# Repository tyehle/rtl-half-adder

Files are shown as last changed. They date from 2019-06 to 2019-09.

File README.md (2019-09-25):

# RTL Half Adder Circuit

board-render-f
board-render-b

A half adder circuit implemented with resistor transistor logic. All essential logic is on the front with through hole parts, and additional lights are surface mount on the back.

# Schematic
schematic
smd-leds

# BOM

| Reference | Value | Part Number | Quantity | Datasheet | Link |
|---|---|---|---|---|---|
| BT1 | Battery_Cell | BAT-HLD-012-THM | 1 | [Datasheet](https://linxtechnologies.com/wp/wp-content/uploads/bat-hld-012-thm.pdf) | [mouser.com](https://www.mouser.com/ProductDetail/BAT-HLD-012-THM) |
| D1 D2 | Red | LTL-4223 | 2 | [Datasheet](https://optoelectronics.liteon.com/upload/download/DS20-2003-313/LTL-4223-032A.pdf) | [mouser.com](https://www.mouser.com/ProductDetail/LTL-4223) |
| D3 D4 | Green | LTL-4233 | 2 | [Datasheet](https://optoelectronics.liteon.com/upload/download/DS-20-92-1097/4233DG.pdf) | [mouser.com](https://www.mouser.com/ProductDetail/LTL-4233) |
| D10 D11 D12 D13 D14 D15 D16 D17 D18 D19 D20 D21 D22 D23 D24 D25 D26 D27 D5 D6 D7 D8 D9 | Yellow | LTST-C230KSKT | 23 | [Datasheet](https://optoelectronics.liteon.com/upload/download/DS22-2000-254/LTST-C230KSKT.pdf) | [mouser.com](https://www.mouser.com/ProductDetail/859-LTST-C230KSKT) |
| Q16 Q17 Q18 Q19 | Q_NPN_BEC | MMBT3904,215 | 4 | [Datasheet](https://assets.nexperia.com/documents/data-sheet/MMBT3904.pdf) | [mouser.com](https://www.mouser.com/ProductDetail/MMBT3904215) |
| Q1 Q10 Q11 Q12 Q13 Q14 Q15 Q2 Q3 Q4 Q5 Q6 Q7 Q8 Q9 | Q_NPN_EBC | 2N3904BU | 15 | [Datasheet](https://www.onsemi.com/pub/Collateral/2N3904-D.pdf) | [mouser.com](https://www.mouser.com/ProductDetail/2N3904BU) |
| R2 R26 R27 R4 | 510 | CFR-25JR-52-510R  | 4 | [Datasheet](http://www.yageo.com/NewPortal/yageodocoutput?fileName=/pdf/throughhole/Yageo_LR_CFR_2013.pdf) | [mouser.com](https://www.mouser.com/ProductDetail/CFR-25JR-52-510R) |
| R28 R31 R35 R38 | 10k | CR0805-FX-1002ELF | 4 | [Datasheet](https://www.bourns.com/pdfs/chpreztr.pdf) | [mouser.com](https://www.mouser.com/ProductDetail/652-CR0805FX-1002ELF) |
| R29 R30 R32 R33 R34 R36 R37 R39 R40 R41 R42 R43 R44 R45 R46 R47 R48 R49 R50 R51 R52 R53 R54 | 510 | CR0805-FX-5100ELF | 23 | [Datasheet](https://www.bourns.com/pdfs/chpreztr.pdf) | [mouser.com](https://www.mouser.com/ProductDetail/652-CR0805FX-5100ELF) |
| R1 R10 R11 R13 R14 R15 R16 R19 R21 R22 R24 R25 R3 R5 R6 R7 R8 | 10k | CFR-25JT-52-10K | 17 | [Datasheet](http://www.yageo.com/NewPortal/yageodocoutput?fileName=/pdf/throughhole/Yageo_LR_CFR_2013.pdf) | [mouser.com](https://www.mouser.com/ProductDetail/CFR-25JT-52-10K) |
| R12 R17 R18 R20 R23 R9 | 1k | CFR-25JT-52-1K | 6 | [Datasheet](http://www.yageo.com/NewPortal/yageodocoutput?fileName=/pdf/throughhole/Yageo_LR_CFR_2013.pdf) | [mouser.com](https://www.mouser.com/ProductDetail/CFR-25JT-52-1K) |
| SW1 SW2 SW3 | SW_SPDT | EG1218 | 3 | [Datasheet](https://www.e-switch.com/system/asset/product_line/data_sheet/119/EG.pdf) | [mouser.com](https://www.mouser.com/ProductDetail/EG1218) |

# Assembly notes
[PDF](docs/rtl-half-adder-assembly.pdf)

# LICENSE
<a rel="license" href="http://creativecommons.org/licenses/by-nc-sa/4.0/">

</a>

This work is licensed under a [Creative Commons Attribution-NonCommercial-ShareAlike 4.0 International License](http://creativecommons.org/licenses/by-nc-sa/4.0/).

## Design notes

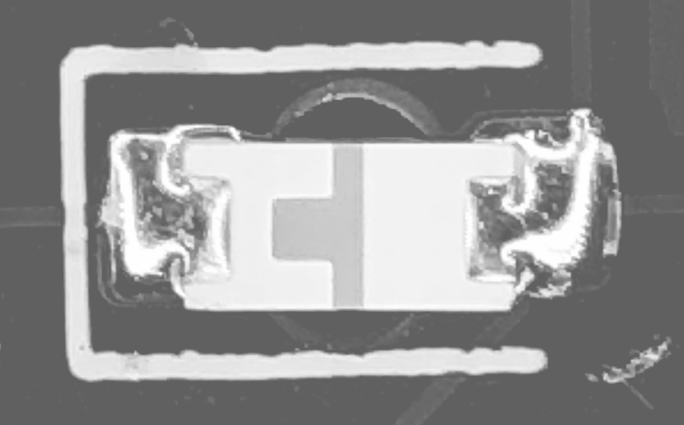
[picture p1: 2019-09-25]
docs/smd-led.jpg

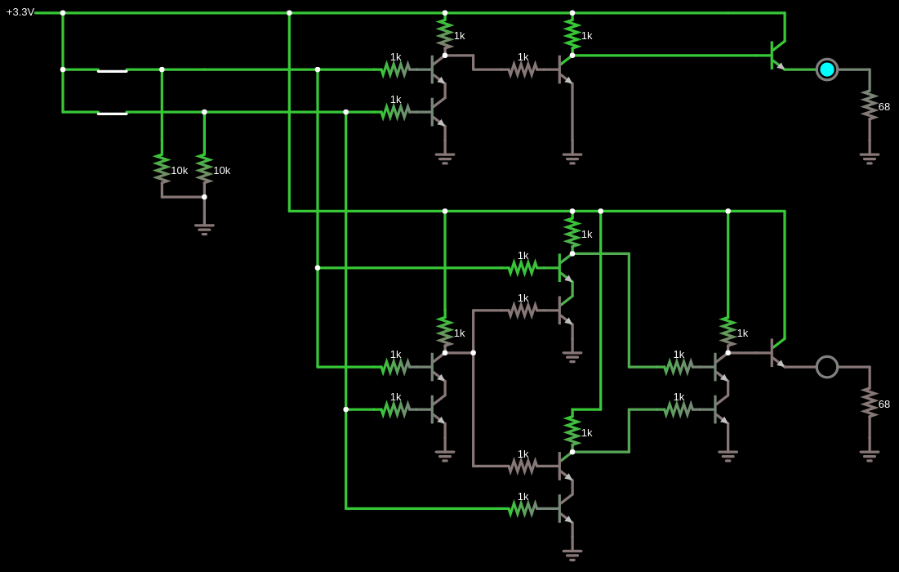
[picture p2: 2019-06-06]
falstad.png

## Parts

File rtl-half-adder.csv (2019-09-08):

Reference | Quantity | Value | Footprint | Datasheet | Link
BT1 | 1 | Battery_Cell | --Project:BatteryHolder_CR1220_THT | https://linxtechnologies.com/wp/wp-content/uploads/bat-hld-012-thm.pdf | https://www.mouser.com/ProductDetail/BAT-HLD-012-THM
D1 D2 | 2 | Red | LED_THT:LED_D5.0mm | https://optoelectronics.liteon.com/upload/download/DS20-2003-313/LTL-4223-032A.pdf | https://www.mouser.com/ProductDetail/LTL-4223
D3 D4 | 2 | Green | LED_THT:LED_D5.0mm | https://optoelectronics.liteon.com/upload/download/DS-20-92-1097/4233DG.pdf | https://www.mouser.com/ProductDetail/LTL-4233
D10 D11 D12 D13 D14 D15 D16 D17 D18 D19 D20 D21 D22 D23 D24 D25 D26 D27 D5 D6 D7 D8 D9 | 23 | Yellow | --Project:LED_1206_ReverseMountSquare1.5mm_HandSolder | https://optoelectronics.liteon.com/upload/download/DS22-2000-254/LTST-C230KSKT.pdf | https://www.mouser.com/ProductDetail/859-LTST-C230KSKT
Q16 Q17 Q18 Q19 | 4 | Q_NPN_BEC | Package_TO_SOT_SMD:SOT-23_Handsoldering | https://assets.nexperia.com/documents/data-sheet/MMBT3904.pdf | https://www.mouser.com/ProductDetail/MMBT3904215
Q1 Q10 Q11 Q12 Q13 Q14 Q15 Q2 Q3 Q4 Q5 Q6 Q7 Q8 Q9 | 15 | Q_NPN_EBC | Package_TO_SOT_THT:TO-92_HandSolder | https://www.onsemi.com/pub/Collateral/2N3904-D.pdf | https://www.mouser.com/ProductDetail/2N3904BU
R2 R26 R27 R4 | 4 | 510 | Resistor_THT:R_Axial_DIN0207_L6.3mm_D2.5mm_P7.62mm_Horizontal | http://www.yageo.com/NewPortal/yageodocoutput?fileName=/pdf/throughhole/Yageo_LR_CFR_2013.pdf | https://www.mouser.com/ProductDetail/CFR-25JR-52-510R
R28 R31 R35 R38 | 4 | 10k | Resistor_SMD:R_0805_2012Metric_Pad1.15x1.40mm_HandSolder | https://www.bourns.com/pdfs/chpreztr.pdf | https://www.mouser.com/ProductDetail/652-CR0805FX-1002ELF
R29 R30 R32 R33 R34 R36 R37 R39 R40 R41 R42 R43 R44 R45 R46 R47 R48 R49 R50 R51 R52 R53 R54 | 23 | 510 | Resistor_SMD:R_0805_2012Metric_Pad1.15x1.40mm_HandSolder | https://www.bourns.com/pdfs/chpreztr.pdf | https://www.mouser.com/ProductDetail/652-CR0805FX-5100ELF
R1 R10 R11 R13 R14 R15 R16 R19 R21 R22 R24 R25 R3 R5 R6 R7 R8 | 17 | 10k | Resistor_THT:R_Axial_DIN0207_L6.3mm_D2.5mm_P7.62mm_Horizontal | http://www.yageo.com/NewPortal/yageodocoutput?fileName=/pdf/throughhole/Yageo_LR_CFR_2013.pdf | https://www.mouser.com/ProductDetail/CFR-25JT-52-10K
R12 R17 R18 R20 R23 R9 | 6 | 1k | Resistor_THT:R_Axial_DIN0207_L6.3mm_D2.5mm_P7.62mm_Horizontal | http://www.yageo.com/NewPortal/yageodocoutput?fileName=/pdf/throughhole/Yageo_LR_CFR_2013.pdf | https://www.mouser.com/ProductDetail/CFR-25JT-52-1K
SW1 SW2 SW3 | 3 | SW_SPDT | --Project:SW_EG1218_SPDT | https://www.e-switch.com/system/asset/product_line/data_sheet/119/EG.pdf | https://www.mouser.com/ProductDetail/EG1218

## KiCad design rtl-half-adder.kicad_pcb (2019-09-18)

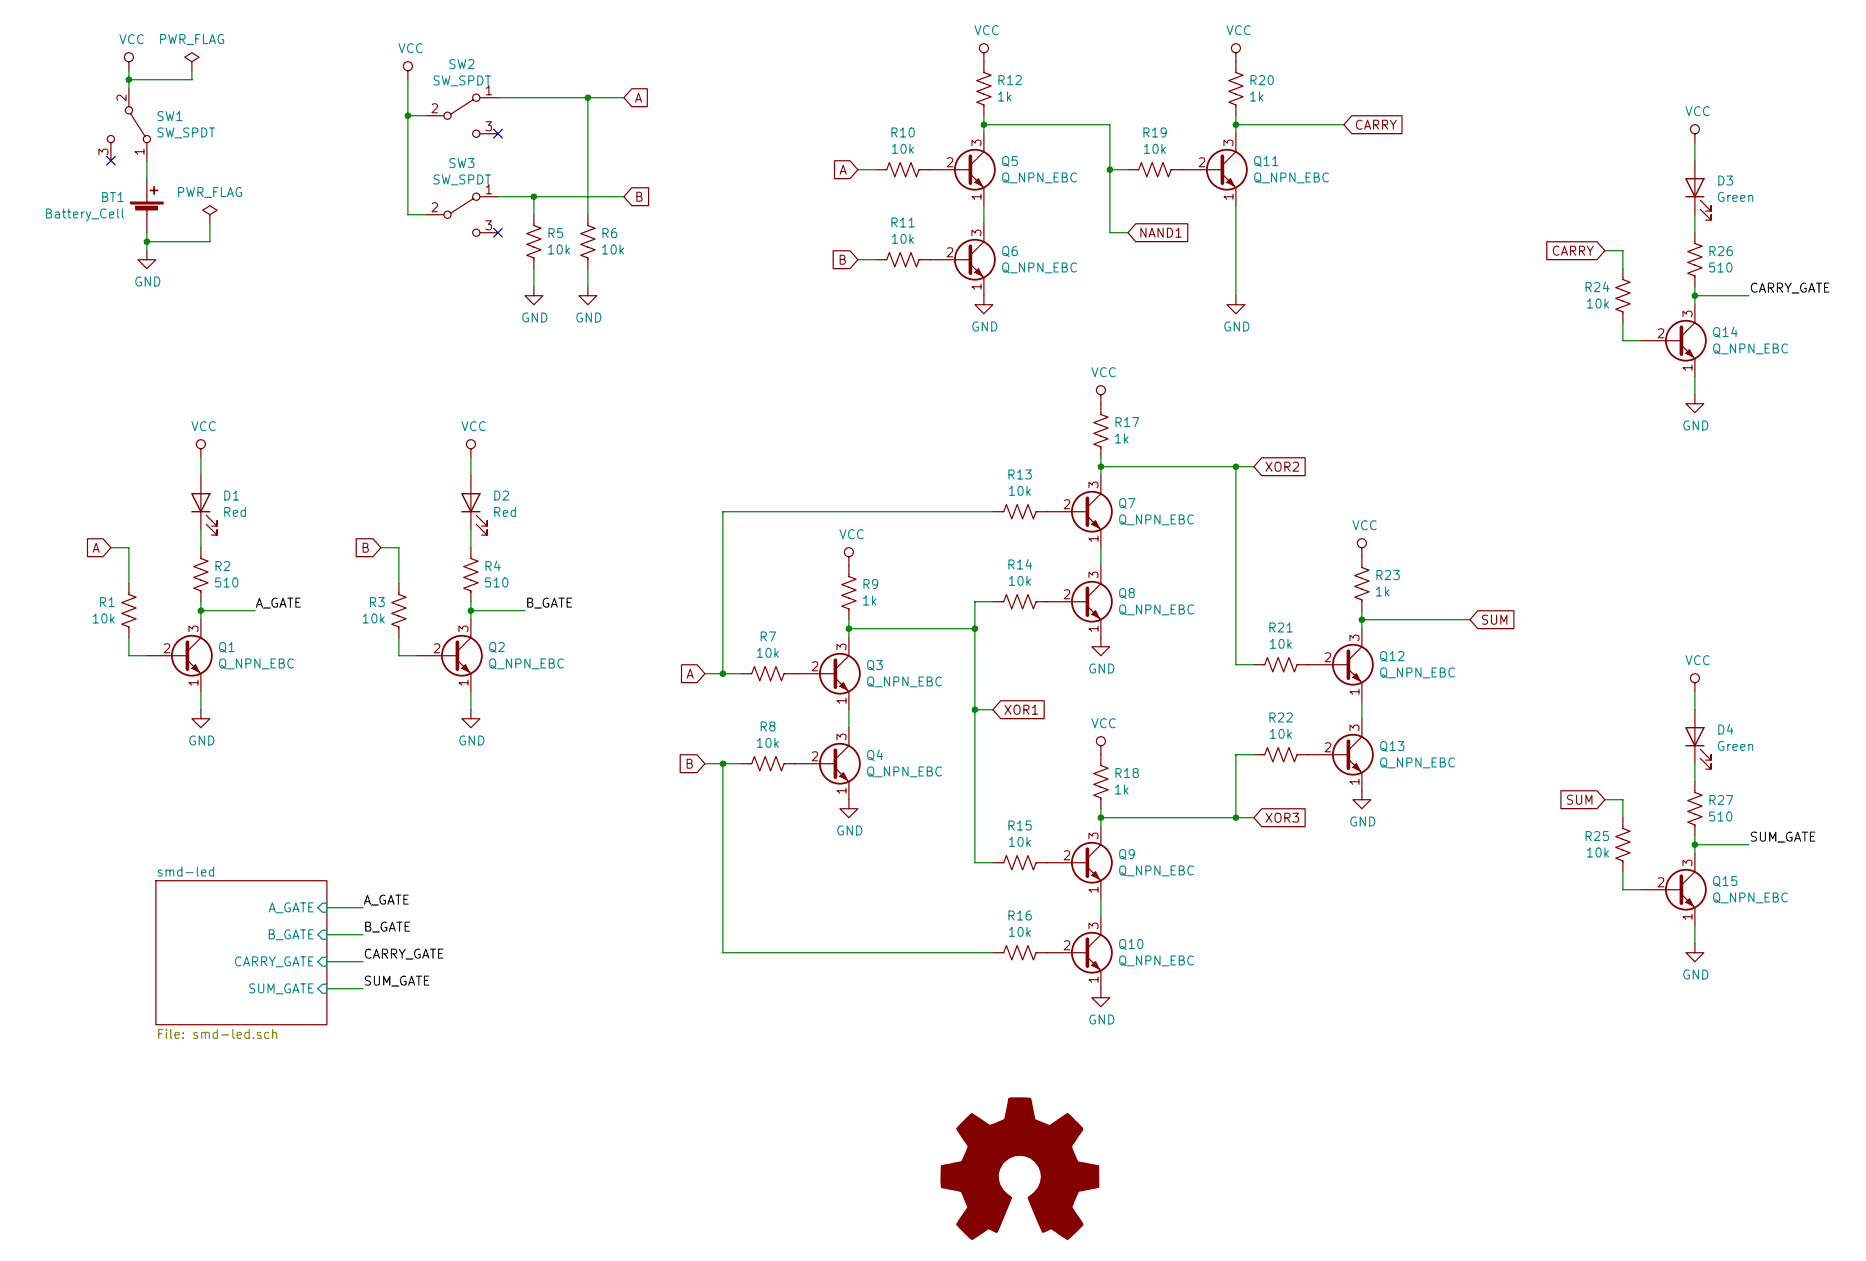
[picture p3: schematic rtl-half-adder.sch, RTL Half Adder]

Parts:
BT1: Battery_Cell; BatteryHolder_CR1220_THT
D1, D2: Red; LED_D5.0mm
D3, D4: Green; LED_D5.0mm
Q1, Q2, Q3, Q4, Q5, Q6, Q7, Q8, Q9, Q10, Q11, Q12, Q13, Q14, Q15: Q_NPN_EBC; TO-92_HandSolder
R1, R3, R5, R6, R7, R8, R10, R11, R13, R14, R15, R16, R19, R21, R22, R24, R25: 10k; R_Axial_DIN0207_L6.3mm_D2.5mm_P7.62mm_Horizontal
R2, R4, R26, R27: 510; R_Axial_DIN0207_L6.3mm_D2.5mm_P7.62mm_Horizontal
R9, R12, R17, R18, R20, R23: 1k; R_Axial_DIN0207_L6.3mm_D2.5mm_P7.62mm_Horizontal
SW1, SW2, SW3: SW_SPDT; SW_EG1218_SPDT

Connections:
/A_GATE: Q1.3 (C), R2.2; also elsewhere on the board
/B_GATE: Q2.3 (C), R4.2; also elsewhere on the board
/CARRY_GATE: Q14.3 (C), R26.2; also elsewhere on the board
/SUM_GATE: Q15.3 (C), R27.2; also elsewhere on the board
A: R1.2, R6.1, R7.2, R10.2, R13.2, SW2.1 (A)
B: R3.2, R5.1, R8.2, R11.2, R16.2, SW3.1 (A)
CARRY: Q11.3 (C), R20.2, R24.2
GND: BT1.2 (-), Q1.1 (E), Q2.1 (E), Q4.1 (E), Q6.1 (E), Q8.1 (E), Q10.1 (E), Q11.1 (E), Q13.1 (E), Q14.1 (E), Q15.1 (E), R5.2, R6.2; also elsewhere on the board
NAND1: Q5.3 (C), R12.2, R19.2; also elsewhere on the board
unnamed: BT1.1 (+), SW1.1 (A)
unnamed: D1.1 (K), R2.1
unnamed: D2.1 (K), R4.1
unnamed: D3.1 (K), R26.1
unnamed: D4.1 (K), R27.1
unnamed: Q1.2 (B), R1.1
unnamed: Q2.2 (B), R3.1
unnamed: Q3.1 (E), Q4.3 (C)
unnamed: Q3.2 (B), R7.1
unnamed: Q4.2 (B), R8.1
unnamed: Q5.1 (E), Q6.3 (C)
unnamed: Q5.2 (B), R10.1
unnamed: Q6.2 (B), R11.1
unnamed: Q7.1 (E), Q8.3 (C)
unnamed: Q7.2 (B), R13.1
unnamed: Q8.2 (B), R14.1
unnamed: Q9.2 (B), R15.1
unnamed: Q10.2 (B), R16.1
unnamed: Q9.1 (E), Q10.3 (C)
unnamed: Q11.2 (B), R19.1
unnamed: Q12.1 (E), Q13.3 (C)
unnamed: Q12.2 (B), R21.1
unnamed: Q13.2 (B), R22.1
unnamed: Q14.2 (B), R24.1
unnamed: Q15.2 (B), R25.1
SUM: Q12.3 (C), R23.2, R25.2
VCC: D1.2 (A), D2.2 (A), D3.2 (A), D4.2 (A), R9.1, R12.1, R17.1, R18.1, R20.1, R23.1, SW1.2 (B), SW2.2 (B), SW3.2 (B); also elsewhere on the board
XOR1: Q3.3 (C), R9.2, R14.2, R15.2; also elsewhere on the board
XOR2: Q7.3 (C), R17.2, R21.2; also elsewhere on the board
XOR3: Q9.3 (C), R18.2, R22.2; also elsewhere on the board

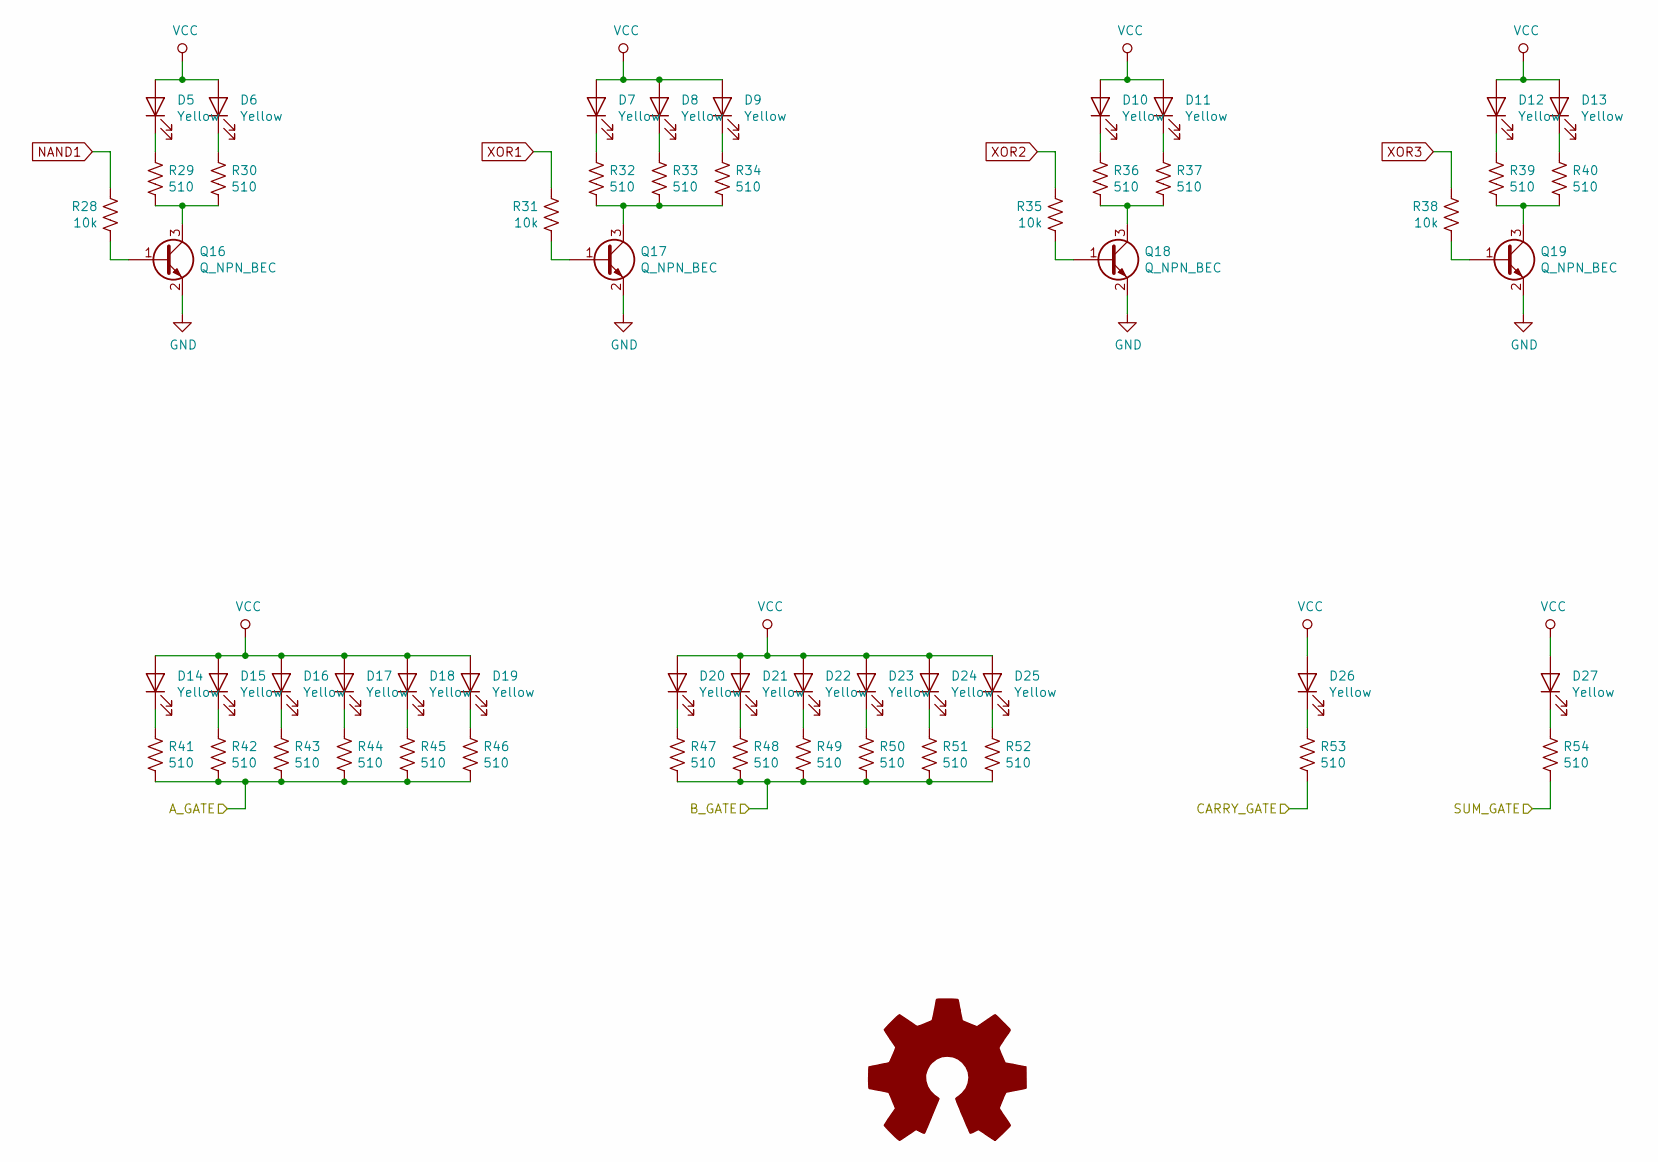
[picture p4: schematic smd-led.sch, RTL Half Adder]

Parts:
D5, D6, D7, D8, D9, D10, D11, D12, D13, D14, D15, D16, D17, D18, D19, D20, D21, D22, D23, D24, D25, D26, D27: Yellow; LED_1206_ReverseMountSquare1.5mm_HandSolder
Q16, Q17, Q18, Q19: Q_NPN_BEC; SOT-23_Handsoldering
R28, R31, R35, R38: 10k; R_0805_2012Metric_Pad1.15x1.40mm_HandSolder
R29, R30, R32, R33, R34, R36, R37, R39, R40, R41, R42, R43, R44, R45, R46, R47, R48, R49, R50, R51, R52, R53, R54: 510; R_0805_2012Metric_Pad1.15x1.40mm_HandSolder

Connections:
/A_GATE: R41.2, R42.2, R43.2, R44.2, R45.2, R46.2; also elsewhere on the board
/B_GATE: R47.2, R48.2, R49.2, R50.2, R51.2, R52.2; also elsewhere on the board
/CARRY_GATE: R53.2; also elsewhere on the board
/SUM_GATE: R54.2; also elsewhere on the board
GND: Q16.2 (E), Q17.2 (E), Q18.2 (E), Q19.2 (E); also elsewhere on the board
NAND1: R28.2; also elsewhere on the board
unnamed: D5.1 (K), R29.1
unnamed: D6.1 (K), R30.1
unnamed: D7.1 (K), R32.1
unnamed: D8.1 (K), R33.1
unnamed: D9.1 (K), R34.1
unnamed: D10.1 (K), R36.1
unnamed: D11.1 (K), R37.1
unnamed: D12.1 (K), R39.1
unnamed: D13.1 (K), R40.1
unnamed: D14.1 (K), R41.1
unnamed: D15.1 (K), R42.1
unnamed: D16.1 (K), R43.1
unnamed: D17.1 (K), R44.1
unnamed: D18.1 (K), R45.1
unnamed: D19.1 (K), R46.1
unnamed: D20.1 (K), R47.1
unnamed: D21.1 (K), R48.1
unnamed: D22.1 (K), R49.1
unnamed: D23.1 (K), R50.1
unnamed: D24.1 (K), R51.1
unnamed: D25.1 (K), R52.1
unnamed: D26.1 (K), R53.1
unnamed: D27.1 (K), R54.1
unnamed: Q16.1 (B), R28.1
unnamed: Q16.3 (C), R29.2, R30.2
unnamed: Q17.1 (B), R31.1
unnamed: Q17.3 (C), R32.2, R33.2, R34.2
unnamed: Q18.1 (B), R35.1
unnamed: Q18.3 (C), R36.2, R37.2
unnamed: Q19.1 (B), R38.1
unnamed: Q19.3 (C), R39.2, R40.2
VCC: D5.2 (A), D6.2 (A), D7.2 (A), D8.2 (A), D9.2 (A), D10.2 (A), D11.2 (A), D12.2 (A), D13.2 (A), D14.2 (A), D15.2 (A), D16.2 (A), D17.2 (A), D18.2 (A), D19.2 (A), D20.2 (A), D21.2 (A), D22.2 (A), D23.2 (A), D24.2 (A), D25.2 (A), D26.2 (A), D27.2 (A); also elsewhere on the board
XOR1: R31.2; also elsewhere on the board
XOR2: R35.2; also elsewhere on the board
XOR3: R38.2; also elsewhere on the board

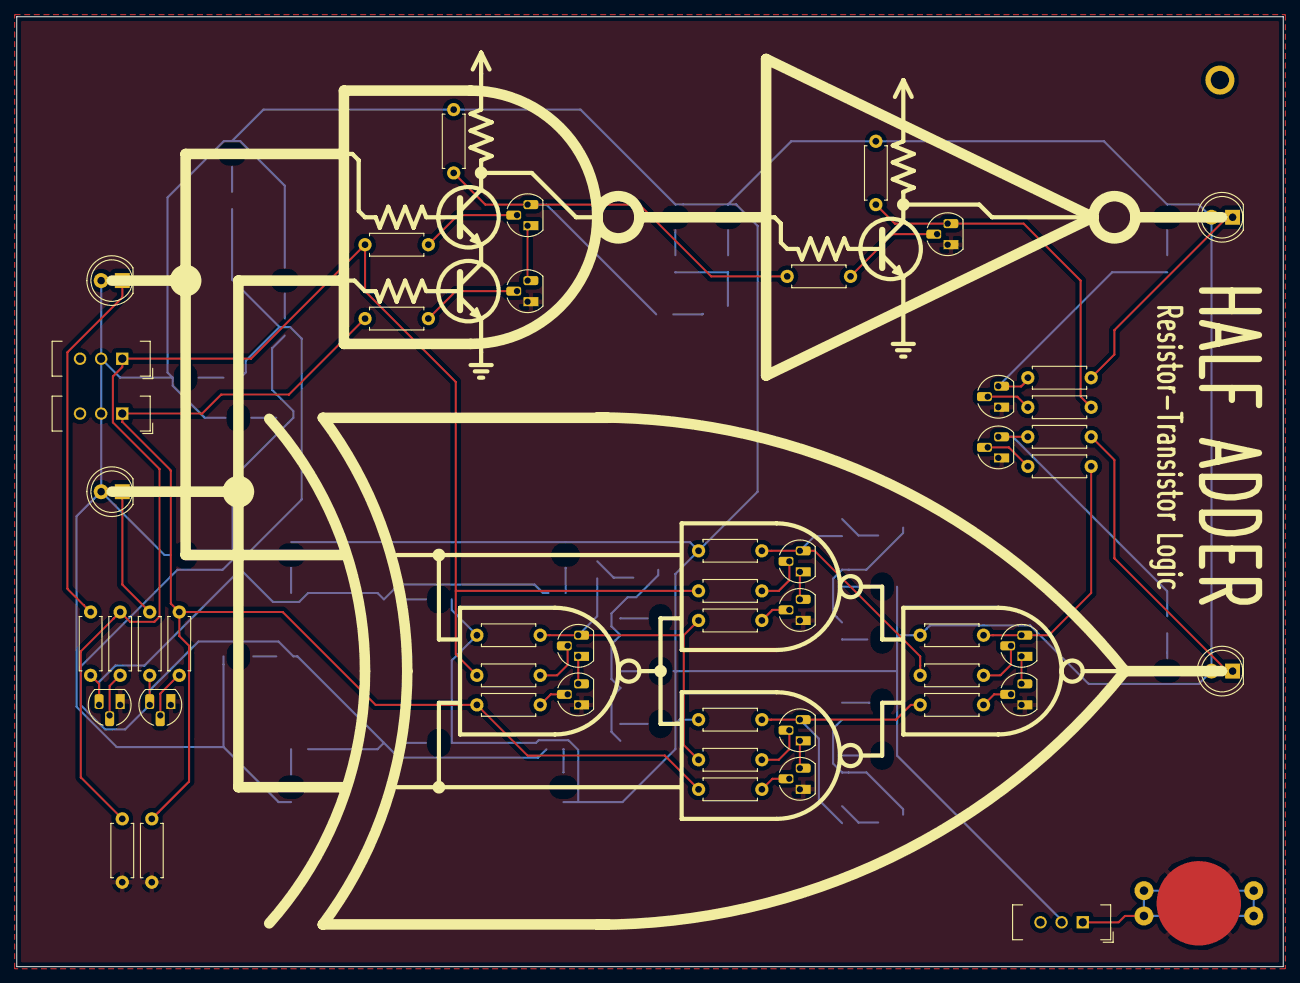
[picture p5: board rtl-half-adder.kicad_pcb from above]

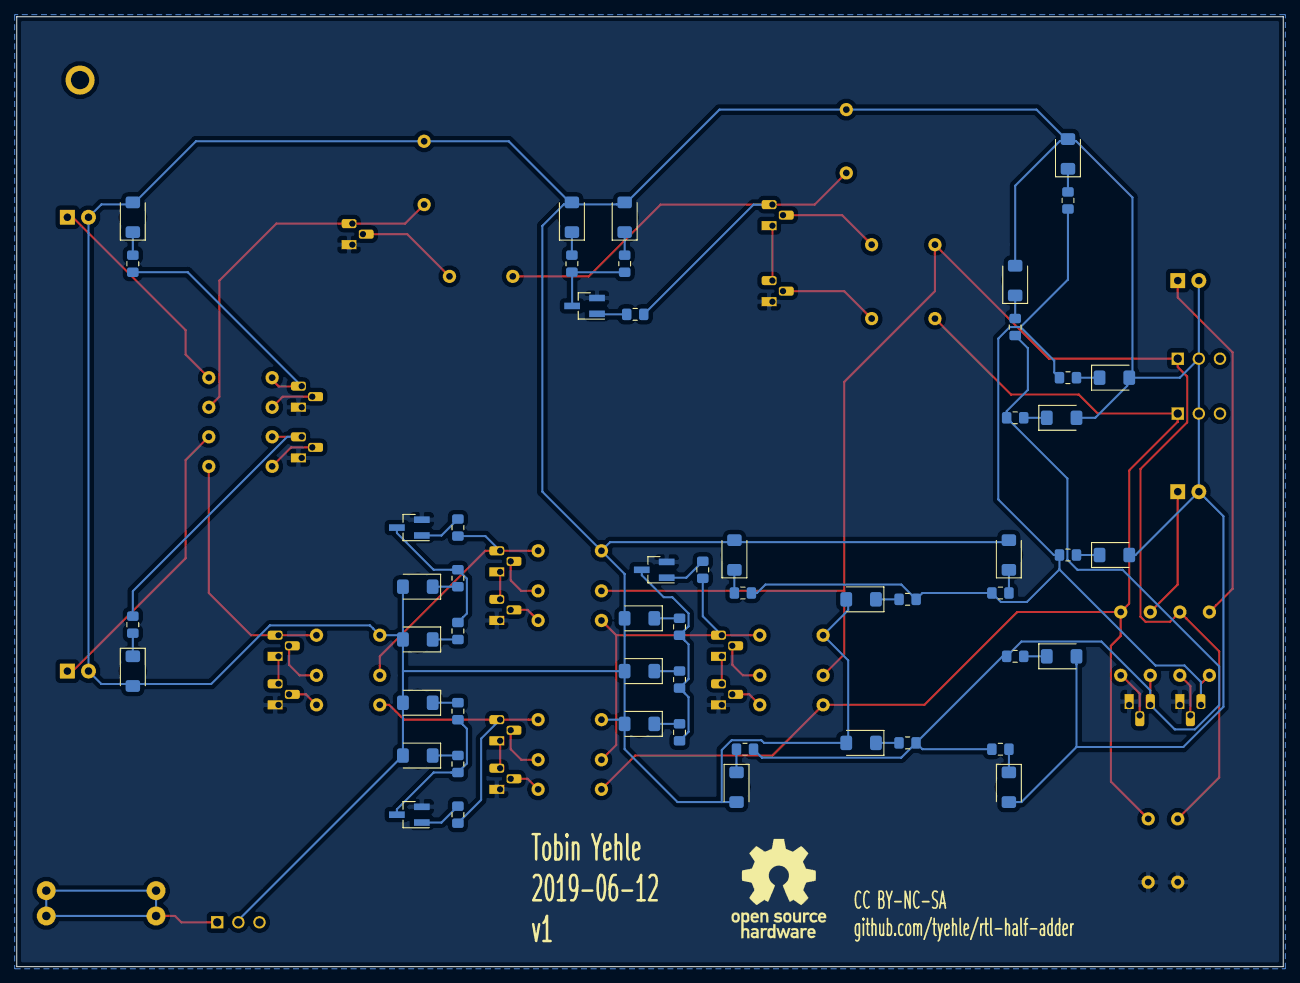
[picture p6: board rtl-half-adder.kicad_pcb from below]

Board: 2 copper layers, 152.4 x 114.3 mm, 104 parts (54 on the bottom side), 70 nets.

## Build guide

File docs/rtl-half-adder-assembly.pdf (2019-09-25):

RTL Half Adder v1 2019-06-12
Tobin Yehle CC BY-NC-SA github.com/tyehle/rtl-half-adder

All the RTL logic is on this side of the board using through hole components. All the surface mount components are optional and go on the other side of the board. The 510 ohm resistors control the brightness of the LEDs. If you prefer them brighter, replace the resistors with smaller ones.

Reference | Value | Part Number | Quantity
BT1 | Battery_Cell | BAT-HLD-012-THM | 1
D1 D2 | Red | LTL-4223 | 2
D3 D4 | Green | LTL-4233 | 2
Q1 - Q15 | Q_NPN_EBC | 2N3904BU | 15
R2 R4 R26 R27 | 510 | CFR-25JR-52-510R | 4
R1 R3 R5 - R8 R10 R11 R13 - R16 R19 R21 R22 R24 R25 | 10k | CFR-25JT-52-10K | 17
R12 R17 R18 R20 R23 R9 | 1k | CFR-25JT-52-1K | 6
SW1 SW2 SW3 | SW_SPDT | EG1218 | 3

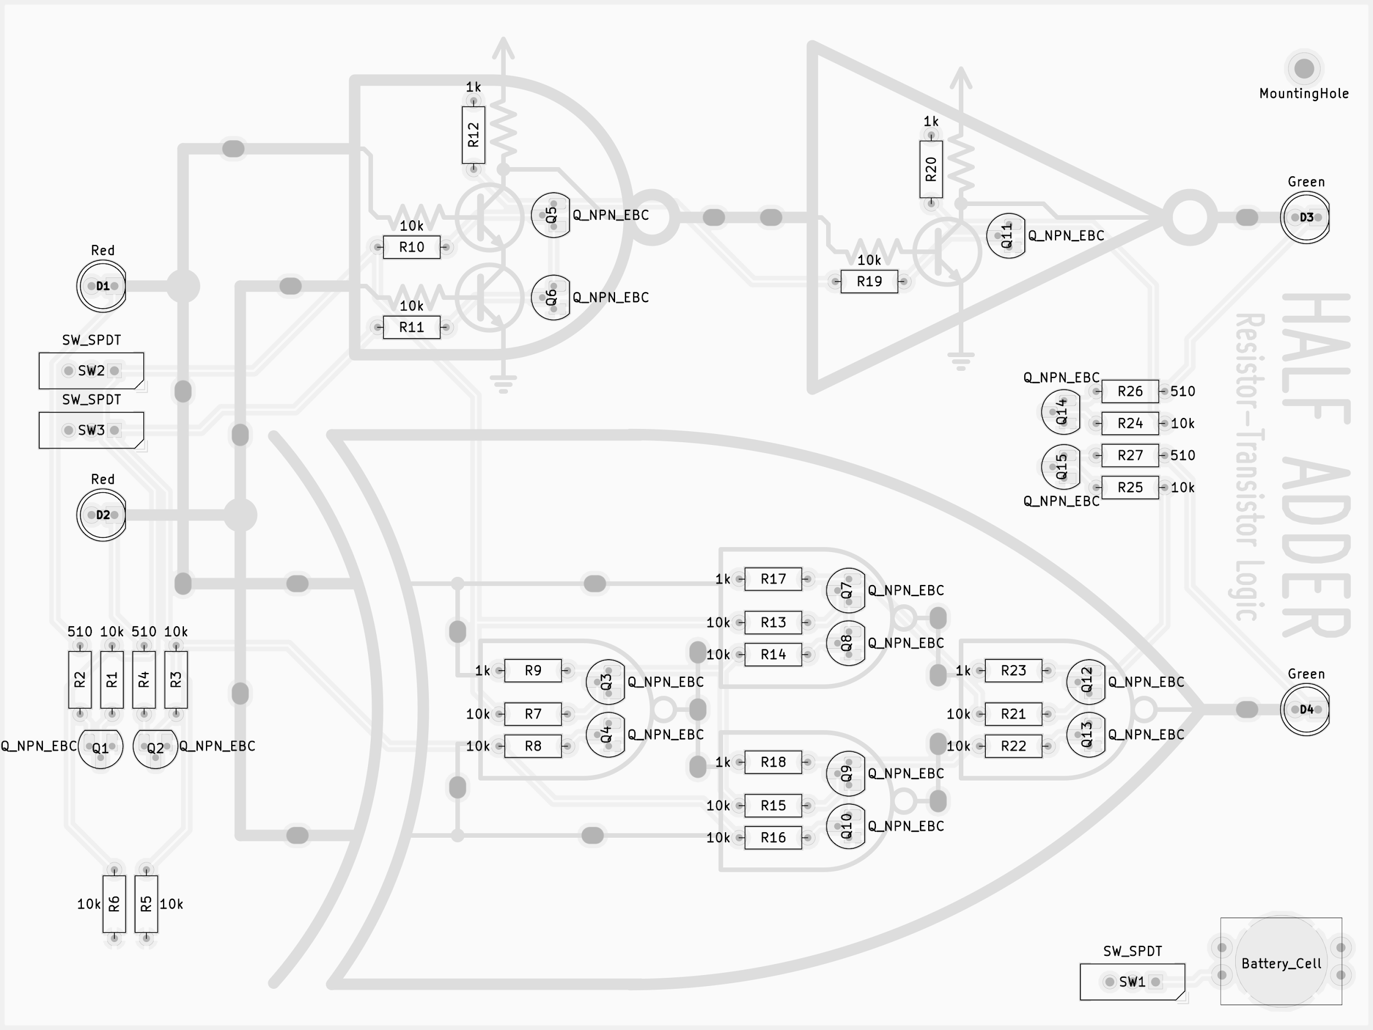
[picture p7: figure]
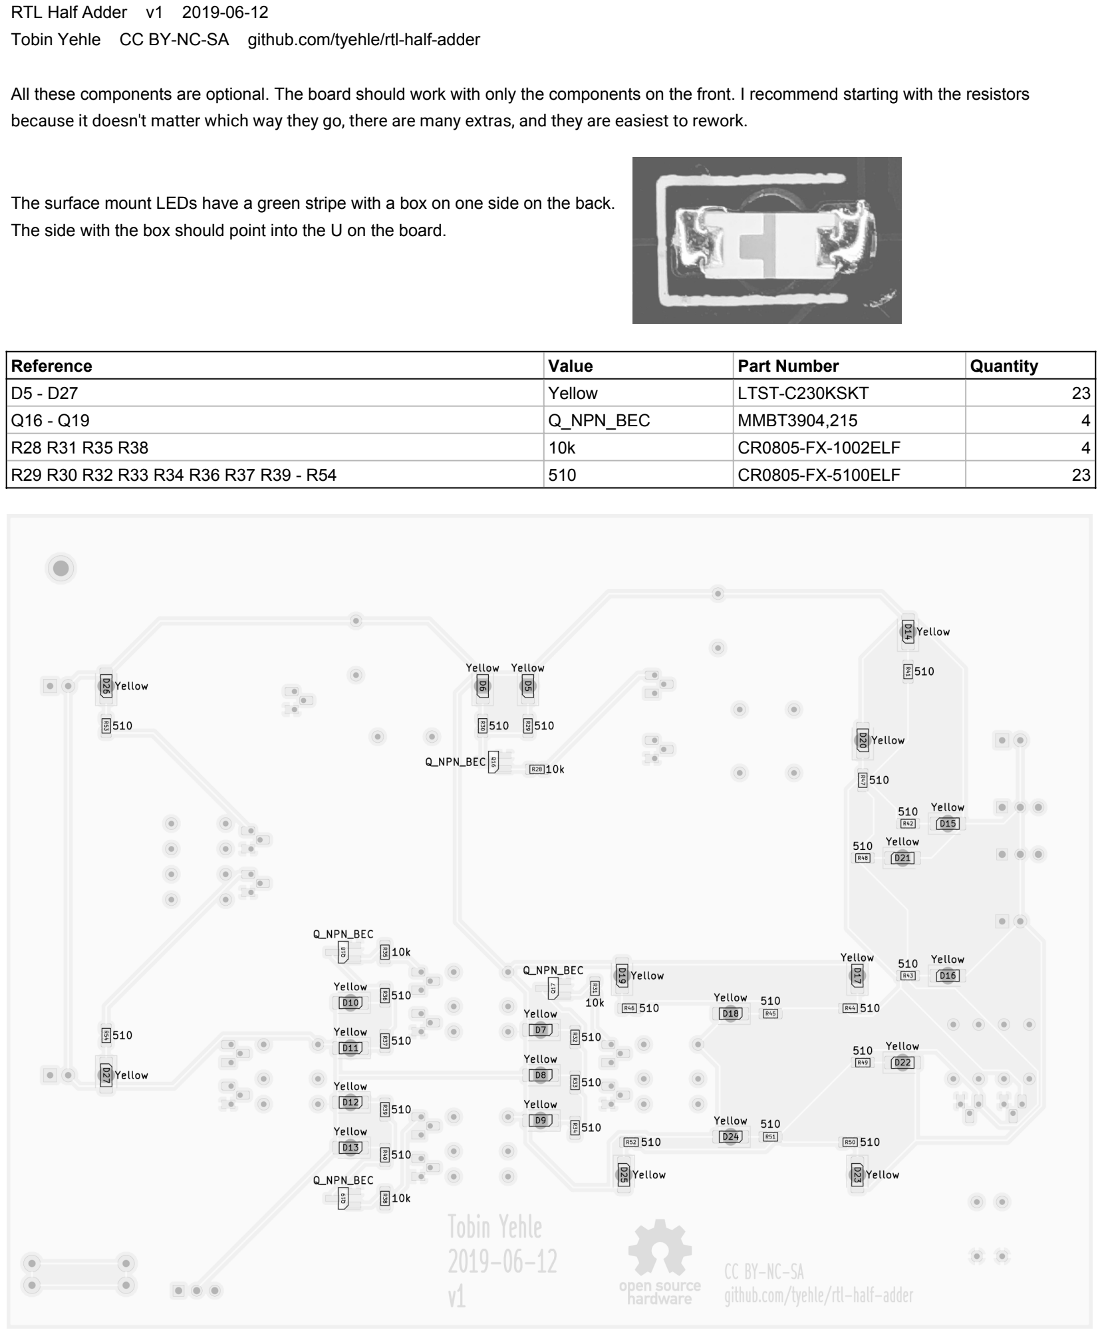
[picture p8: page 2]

RTL Half Adder v1 2019-06-12
Tobin Yehle CC BY-NC-SA github.com/tyehle/rtl-half-adder

All these components are optional. The board should work with only the components on the front. I recommend starting with the resistors because it doesn't matter which way they go, there are many extras, and they are easiest to rework.

The surface mount LEDs have a green stripe with a box on one side on the back. The side with the box should point into the U on the board.

Reference | Value | Part Number | Quantity
D5 - D27 | Yellow | LTST-C230KSKT | 23
Q16 - Q19 | Q_NPN_BEC | MMBT3904,215 | 4
R28 R31 R35 R38 | 10k | CR0805-FX-1002ELF | 4
R29 R30 R32 R33 R34 R36 R37 R39 - R54 | 510 | CR0805-FX-5100ELF | 23

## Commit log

2019-06-06 schematic and xor layout done
    [rtl-half-adder.kicad_pcb, rtl-half-adder.sch]
2019-06-08 through hole components and silk screen done
    [rtl-half-adder.kicad_pcb, rtl-half-adder.sch]
2019-06-09 copy an led footprint with a reverse mount hole to a local lib
2019-06-09 update footprints for smd leds
    [rtl-half-adder.kicad_pcb, rtl-half-adder.sch]
2019-06-09 inter gate led layout done
    [rtl-half-adder.kicad_pcb, rtl-half-adder.sch]
2019-06-10 add battery footprint
    [rtl-half-adder.sch]
2019-06-10 add link and datasheet for battery clip
    [rtl-half-adder.sch]
2019-06-11 update schematic
    [rtl-half-adder.sch, smd-led.sch]
2019-06-11 refactor numeric assignments
    [rtl-half-adder.kicad_pcb, rtl-half-adder.sch, smd-led.sch]
2019-06-11 fix front fab layer
    [rtl-half-adder.kicad_pcb, rtl-half-adder.sch]
2019-06-11 put notes on the back
    [rtl-half-adder.kicad_pcb]
2019-06-12 full smd led array layout done
    [rtl-half-adder.kicad_pcb, smd-led.sch]
2019-06-12 layout all done
    [rtl-half-adder.kicad_pcb]
2019-06-13 fix issues with some tracks
    [rtl-half-adder.kicad_pcb]
2019-06-14 add sheet annotations
    [rtl-half-adder.kicad_pcb, rtl-half-adder.sch, smd-led.sch]
2019-06-14 add schematic svgs
2019-06-14 add gerbers
    [rtl-half-adder-B.Cu.gbl, rtl-half-adder-B.Fab.gbr, rtl-half-adder-B.Mask.gbs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]
2019-06-14 add black and white board docs
2019-06-14 add svg board renders
2019-06-14 rename schematic svg
2019-07-31 change led footprint
    [rtl-half-adder.kicad_pcb, rtl-half-adder.sch, smd-led.sch]
2019-07-31 regen gerbers
    [rtl-half-adder-B.Cu.gbl, rtl-half-adder-B.Fab.gbr, rtl-half-adder-B.Mask.gbs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]
2019-09-04 add updated smd led footprint
    [smd-led.sch]
2019-09-04 more part links and BOM
    [rtl-half-adder.csv, rtl-half-adder.sch]
2019-09-04 add io led specs
    [rtl-half-adder.sch, smd-led.sch]
2019-09-08 finish bom
    [rtl-half-adder.csv, rtl-half-adder.sch, smd-led.sch]
2019-09-18 update fab layer with new labels
    [rtl-half-adder.kicad_pcb]
2019-09-18 add bom to readme
2019-09-25 add assembly notes
